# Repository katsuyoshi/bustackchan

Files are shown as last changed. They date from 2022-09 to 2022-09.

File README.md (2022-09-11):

# ﾊﾞｽﾀｯｸﾁｬﾝ (BUSTACK-chan)

BUSTACK-chan

[ｽﾀｯｸﾁｬﾝ](https://protopedia.net/prototype/2345)にインスパイアされて作りました。

ﾊﾞｽﾀｯｸﾁｬﾝ という名前の思いつきからのスタートでした。

protopediaのページも併せてご覧ください。

https://protopedia.net/prototype/3251

## 材料

|材料|数量|備考|
|:--|--:|:--|
|[M5Stack Basic]()|1||
|[M5Stack用NeoPixel互換 LEDテープ 10 cm](https://www.switch-science.com/catalog/5208/)|1||
|[M5Stack用GROVE互換ケーブル 10 cm](https://www.switch-science.com/catalog/5213/)|1||
|[ｽﾀｯｸﾁｬﾝの基板]()|1|ｽﾀｯｸﾁｬﾝの公開されているGithubページに[データ](https://github.com/meganetaaan/stack-chan/tree/main/schematics/m5-pantilt/gerber)があります。[nyaru lab](https://booth.pm/ja/items/4094998)さんが販売している様です。|
|[リチウムイオンポリマー電池](https://www.switch-science.com/catalog/3118/)|1||
|[M5Stack用2 x 15ピンヘッダ](https://www.switch-science.com/catalog/3654/)|1||
|その他ピンヘッダ、コンデンサ、抵抗など||[ｽﾀｯｸﾁｬﾝの基板組み立て](https://github.com/meganetaaan/stack-chan/blob/main/schematics/README_ja.md)説明のPWMサーボの項を参考にしてください。|

## 作り方

- 3Dプリンターでボディ、ヘッド、窓、シャーシ、タイヤを印刷します。
  |パーツ|備考|
  |:--|:--|
  |[ボディ](models/body%20v19.gcode)|加工が必要です。|
  |[ヘッド](models/head%20v4.gcode)||
  |[窓](models/window%20v2.gcode)|左右と後部の3つが組みになっています。|
  |[シャーシ](models/chassis3%20v6.gcode)||
  |[タイヤ](models/tire%20v3.gcode)|4本組みになってます。|

- ポディでM5StackのUSB-Cコネクターと電源ボタンの部分が塞がれているので、[発泡スチロールカッター](https://getnavi.jp/zakka/464317/)などでコネクターが差し込みできる様にボディにスリットを入れます。(*1)

- ボディに窓をはめる際は平やすりなどで窓枠の下の方を少々削って調整する必要があります。左右も若干削った方が良いかもしれません。窓をボディにはめ、ピッタリの場合はそのままで問題ありませんが、緩い場合は接着剤などを使ってください。

- 竹串か竹籤(φ2.5mm)を52mmの長さで切り2本用意します。

- シャーシの穴の空いているところに竹串を通し両端にタイヤを差し込みます。入りずらい場合は竹串の先端を少し削ってください。

- ｽﾀｯｸﾁｬﾝ基板を組み立てます。オリジナル[ｽﾀｯｸﾁｬﾝの基板組み立て](https://github.com/meganetaaan/stack-chan/blob/main/schematics/README_ja.md)説明のPWMサーボの項を参考に組み立てます。

- 基板をM5Stackに付けます。

- LEDテープをシャーシに付けます。(*2) マッチ箱くらいの物を貼り付けその側面にLEDテープを貼り付けます。

- リチウムイオンポリマー電池をその上に貼り付けます。

- GROVE互換ケーブルでLEDテープと基板を接続します。基板側はピッチが合わないのでケーブルを切断しコネクターをつける加工をし、J3ピンヘッダーにGND側を合わせて差し込みます。

- リチウムイオンポリマー電池を基板と接続します。

- M5Stackをシャーシーの先頭部に差し込みます。この時ボタンが上になる様にします。

- ボディをシャーシーに被せます。

- ヘッドをボディの穴に合わせて差し込みます。

- プログラムを書き込みます。PlatformIOを使っています。
  - 使用しているライブラリーはplatformio.iniをご覧ください。

*1 将来的にはモデルに反映したいと思っています。  
*2 将来的にはモデルに取り付け用の仕掛けをつけたいと思います。

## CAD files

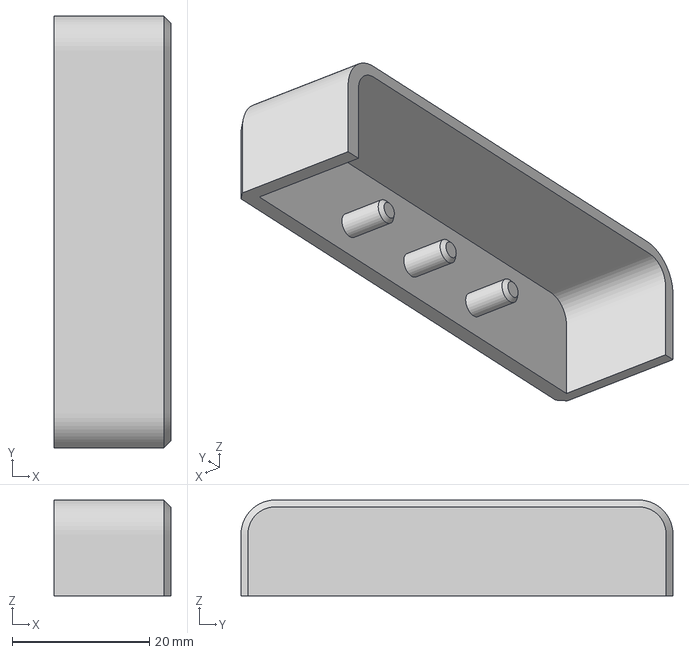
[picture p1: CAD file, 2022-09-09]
models/head v5.3mf
17.0 x 63.0 x 14.0 mm

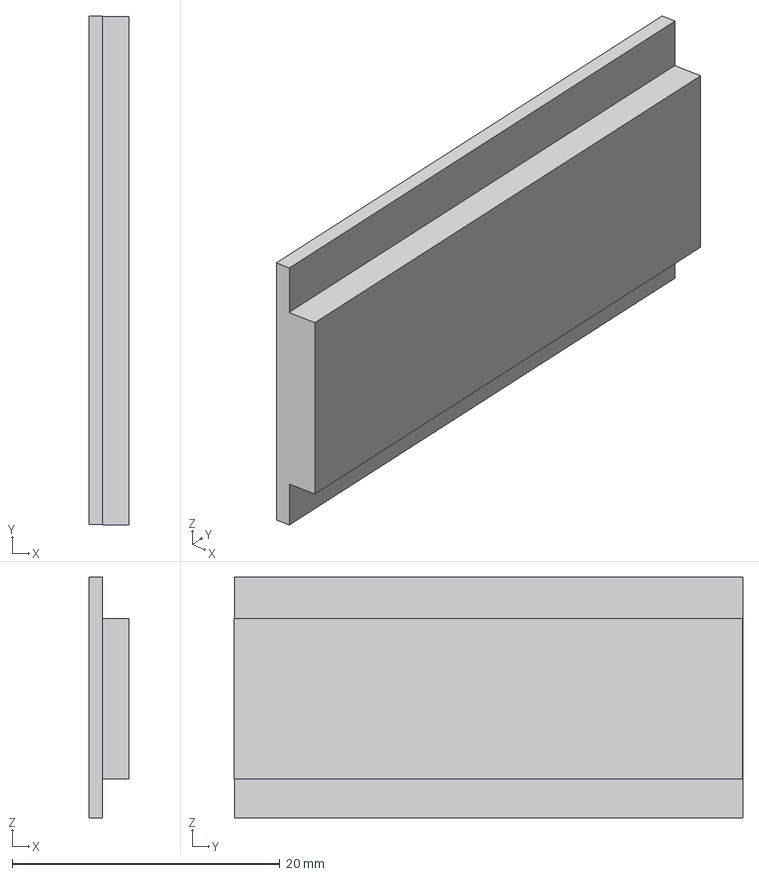
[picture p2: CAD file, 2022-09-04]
models/window2 v2.3mf
3.00 x 38.0 x 18.0 mm

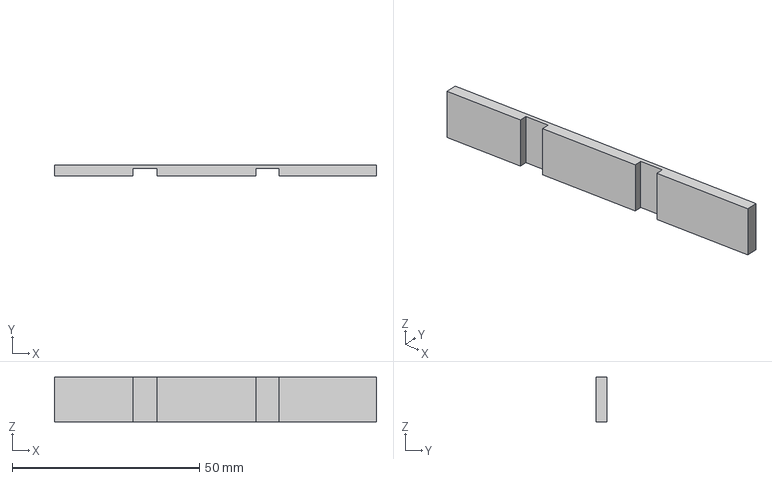
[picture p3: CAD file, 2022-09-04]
models/window1-left v2.3mf
86.0 x 3.00 x 12.0 mm

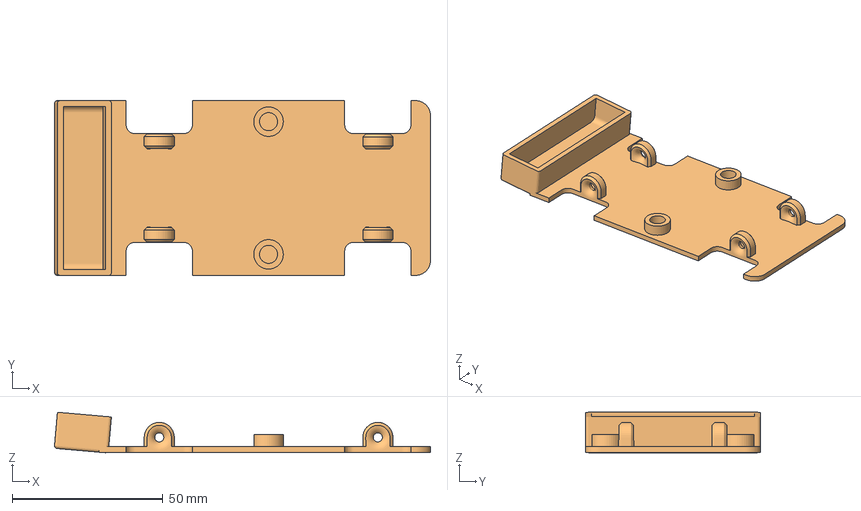
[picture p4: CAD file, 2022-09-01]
models/chassis3 v6.3mf
124.7 x 58.0 x 13.4 mm
ボディ1 x 2

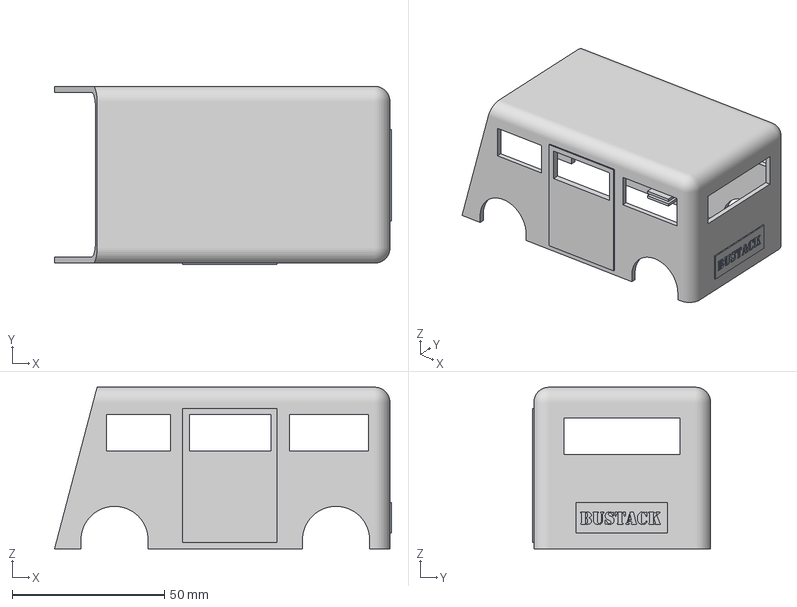
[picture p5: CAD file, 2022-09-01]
models/body v19.3mf
110.5 x 58.5 x 53.0 mm

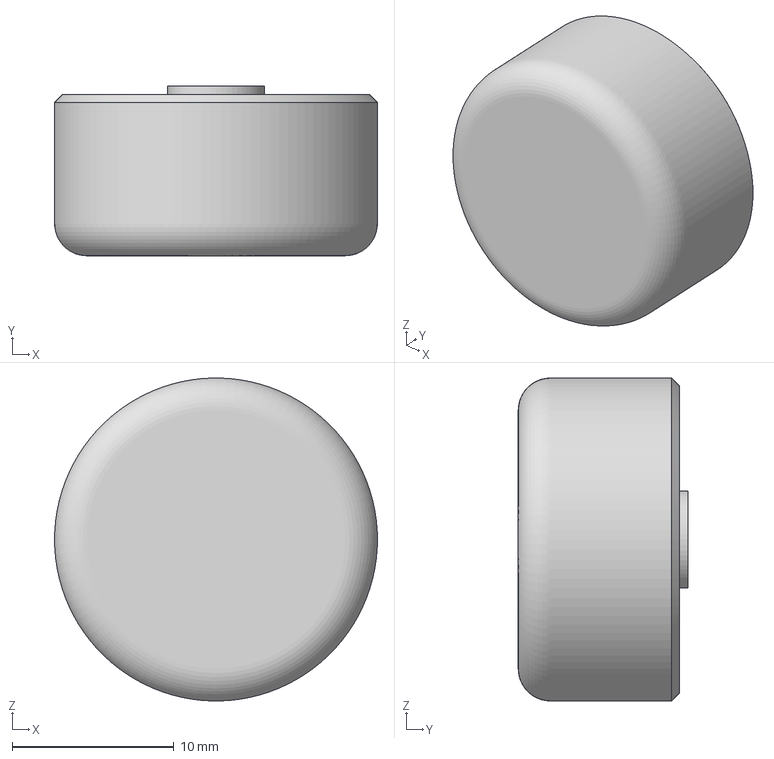
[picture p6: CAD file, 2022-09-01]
models/tire v3.3mf
20.0 x 10.5 x 20.0 mm

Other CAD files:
models/window1-right v2.3mf
models/head v4.3mf

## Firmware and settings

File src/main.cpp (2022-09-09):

#include <Arduino.h>
#include <M5Unified.h>
#include <WiFiMulti.h>
#include <Avatar.h>
#include <NeoPixelBus.h>
#include "ServoEasing.hpp"
#include "faces/bus_face.h"
#include <aquestalk.h>
#include "env.h"

using namespace m5avatar;

//******************************
// defines

//#define SERVO_PIN           5
#define PIXEL_PIN             2

//#define SERVO_START_DEGREE  90

#define colorSaturation 128


// LEDの点滅パターン
typedef enum led_pattern_id
 {
  LPNone,
  LPLeft,
  LPRight,
  LPStop,
};

// AquesTalkのフレーズ
typedef enum phrase_id {
  PHGreeting,
  PHJousha,
  PHOriru,
  PHSutakuNumaYuki,
  PHGrooto,
  PHArigato,
  PHTugiwa,
  PHTugiTomarimasu,
  PHTomarimasu,
  PHTrunLeft,
  PHTrunRight,
};

// 行き先表示
typedef enum heading_id {
  HDBustack,
  HDStackPond,
  HDGurutto,
};



//******************************
// Variables

// for avator
static Avatar avatar;
//static ServoEasing servo;
static ColorPalette cp;

// for WiFi
static WiFiMulti wifiMulti;


static double pi = atan(1.0) * 4.0;

// for AquesTalk
/// set M5Speaker virtual channel (0-7)
static constexpr uint8_t m5spk_virtual_channel = 0;
static constexpr uint8_t LEN_FRAME = 32;
static uint32_t workbuf[AQ_SIZE_WORKBUF];
static TaskHandle_t task_handle = nullptr;
volatile bool is_talking = false;

static int volume = 127;
static bool vol_up = true;
static bool vol_changing = false;

static phrase_id speaking_phrase = PHGreeting;

// @see: https://www.a-quest.com/demo/index.html
// 上記サイトで規則音声合成テキストを生成する。
// utilsのkana2romajiでローマ字に変換する。
//
// 例)
// 「どーも、バスタックちゃんです。」
//    |
//    V Convert
// 「ド'ーモ、バ'_ス/タ'ッ_クチャンデ_ス。」
//
// % ./kana2romaji "ド'ーモ、バ'_ス/タ'ッ_クチャンデ_ス。"
// #=> "do'-mo,ba'_su/ta'_kutyan;de_su."
//

static const char *phrases[] = {
  "do'-mo,ba'_su/ta'_kutyan;de_su.",
  "onorino+katawa/botan;o/o_sitekudasa'i.",
  "oorinokatawa/bo'tan;o/o_sitekudasa'i.",
  "kono/ba'suwa/_sutakku'numa/yu'kide_su.",
  "kono/ba'suwa/a_kitake'n;naio/syu-kaisuru/guru'to/a'_kitade_su.",
  "gozyo-sya/ari'gato-+gozaima'_sita.matano/goriyo-o/oma_ti/siteorima'_su.",
  "tugi'wa.",
  "tugi'/tomarima'_su.",
  "tomarima'_su.",
  "hidarini/magarima'_su.gotyu-ikudasa'i.",
  "migini/magarima'_su.gotyu-ikudasa'i.",
};

static const char *municipalities[] = {
  "higasinarusemura",
  "yuzawa'_si.",
  "ugo'mati",
  "yokote'_si.",
  "misato'tyo-",
  "daise'n;_si.",
  "sen;boku'_si.",
  "kazuno'_si.",
  "kosaka'mati",
  "o-date'_si.",
  "huzisato'mati",
  "happou'tyo-",
  "nosiro'_si.",
  "_kitaa_kita'_si.",
  "kamikoanimura",
  "mitane'tyo-",
  "oogatamura",
  "oga'_si.",
  "katagami'_si.",
  "ikawa'mati",
  "hatiro-gata'mati",
  "gozyo-me'mati",
  "a_kita'_si.",
  "yurihon;zyo'-_si.",
  "nikaho'si"
};


// for BUSTACK
volatile bool boarding = false;
volatile bool stop_requested = false;
static int next_time = 0;

static heading_id heading_for = HDBustack;

static const char *heading_titles[] = {
  "　　バスタックちゃん　　",
  "　　 スタック沼行き 　　",
  "　　　ぐるっと秋田　　　",
};

int interval_between_stops = 1;


// for LEDs
static led_pattern_id
 led_pat = LPNone;
const uint16_t PixelCount = 15;
const uint8_t AnimationChannels = 1;
NeoPixelBus<NeoGrbFeature, Neo800KbpsMethod> strip(PixelCount, PIXEL_PIN);

RgbColor red(colorSaturation, 0, 0);
RgbColor green(0, colorSaturation, 0);
RgbColor blue(0, 0, colorSaturation);
RgbColor yellow(colorSaturation, colorSaturation, 0);
RgbColor orange(colorSaturation, colorSaturation * 165 / 255, 0);
RgbColor white(colorSaturation);
RgbColor black(0);


// for NTP sync

time_t time_synced_at = 0;
uint32_t millis_since_time_synced;

const char* ntpServer = "ntp.nict.jp";
const long  gmtOffset_sec = 3600 * 9;
const int   daylightOffset_sec = 0;



//******************************
// functions

static void SetRandomSeed()
{
    uint32_t seed;

    // random works best with a seed that can use 31 bits
    // analogRead on a unconnected pin tends toward less than four bits
    seed = analogRead(0);
    vTaskDelay(1);

    for (int shifts = 3; shifts < 31; shifts += 3)
    {
        seed ^= analogRead(0) << shifts;
        vTaskDelay(1);
    }

    randomSeed(seed);
}


// for LEDs
static void set_left_led() {
  for (int i = 0; i < PixelCount; i++) {
    if (i >= 9) {
      strip.SetPixelColor(i, orange);
    } else {
      strip.SetPixelColor(i, black);
    }
  }
  strip.Show();
}

static void set_right_led() {
  for (int i = 0; i < PixelCount; i++) {
    if (i < 6) {
      strip.SetPixelColor(i, orange);
    } else {
      strip.SetPixelColor(i, black);
    }
  }
  strip.Show();
}

static void set_stop_led() {
  for (int i = 0; i < PixelCount; i++) {
    if (i >= 6 && i < 9) {
      strip.SetPixelColor(i, red);
    } else {
      strip.SetPixelColor(i, black);
    }
  }
  strip.Show();
}

static void set_blank_led() {
  for (int i = 0; i < PixelCount; i++) {
    strip.SetPixelColor(i, black);
  }
  strip.Show();
}

static void led_task(void*)
{
  strip.Begin();
  while(true) {
    switch(led_pat) {
      case LPLeft:
        set_left_led();
        vTaskDelay(250);
        set_blank_led();
        vTaskDelay(250);
        break;
      case LPRight:
        set_right_led();
        vTaskDelay(250);
        set_blank_led();
        vTaskDelay(250);
        break;
      case LPStop:
        set_stop_led();
        vTaskDelay(100);
        break;
      default:
        set_blank_led();
        vTaskDelay(10);
        break;
    }
  }
}



// for AquesTalk

static void talk_task(void*)
{
  int16_t wav[3][LEN_FRAME];
  int tri_index = 0;
  for (;;)
  {
    ulTaskNotifyTake( pdTRUE, portMAX_DELAY ); // wait notify
    while (is_talking)
    {
      uint16_t len;
      if (CAqTkPicoF_SyntheFrame(wav[tri_index], &len)) { is_talking = false; break; }
      M5.Speaker.playRaw(wav[tri_index], len, 8000, false, 1, m5spk_virtual_channel, false);
      tri_index = tri_index < 2 ? tri_index + 1 : 0;
    }
  }
}

static void lip_sync_task(void *args)
{
  DriveContext *ctx = reinterpret_cast<DriveContext *> (args);
  Avatar *avatar = ctx->getAvatar();
  while(true) {
    if (is_talking) {
      float open = random(0,99) / 100.00;
      avatar->setMouthOpenRatio(open);
    } else {
      avatar->setMouthOpenRatio(1.0);
    }
    vTaskDelay(5);
  }
}

/// 音声再生の終了を待機する;
static void waitAquesTalk(void)
{
  while (is_talking) { vTaskDelay(1); }
}

/// 音声再生を停止する;
static void stopAquesTalk(void)
{
  if (is_talking) { is_talking = false; vTaskDelay(1); }
}

/// 音声再生を開始する。(再生中の場合は中断して新たな音声再生を開始する) ;
static void playAquesTalk(const char *koe)
{
  stopAquesTalk();

  //M5.Display.printf("Play:%s\n", koe);

  int iret = CAqTkPicoF_SetKoe((const uint8_t*)koe, 100, 0xFFu);
  //if (iret) { M5.Display.println("ERR:CAqTkPicoF_SetKoe"); }

  is_talking = true;
  xTaskNotifyGive(task_handle);
}

void speak(phrase_id id) {
  speaking_phrase = id;
  playAquesTalk(phrases[id]);
}

void speak_next_stop() {

  // 停止ボタンが押されていたら停止アナウンスする
  if (stop_requested) {
    switch(random(3)) {
      case 0:
        speak(PHTrunLeft);
        led_pat = LPLeft;
        vTaskDelay(10000);
        break;
      case 1:
        speak(PHTrunRight);
        led_pat = LPRight;
        vTaskDelay(10000);
        break;
    }
    speak(PHTomarimasu);
    led_pat = LPStop;
    waitAquesTalk();
    vTaskDelay(1000);

    speak(PHArigato);
    waitAquesTalk();
    vTaskDelay(5000);

    led_pat = LPNone;
    stop_requested = false;
    boarding = false;

    const char *title = heading_titles[HDBustack];
    BusFace *face = (BusFace *)avatar.getFace();
    face->set_heading_title(title);
    face->set_stop_requested(stop_requested);
  }

  if (boarding) {
    int i = next_time % 24;
    if (i == 23) {
      speak(PHGrooto);
    } else {
      speak(PHTugiwa);
      waitAquesTalk();
      playAquesTalk(municipalities[i]);
      waitAquesTalk();
      vTaskDelay(500);
      speak(PHOriru);
    }
  }
}


// 乗車時処理

void get_on_for(heading_id id)
{
  const char *title = heading_titles[id];
  BusFace *face = (BusFace *)avatar.getFace();
  face->set_heading_title(title);

  switch(id) {
    case HDStackPond:
      speak(PHSutakuNumaYuki);
      break;
    case HDGurutto:
      speak(PHGrooto);
      break;
  }
  boarding = true;
}



// for time management

void syncTime() {
  configTime(0, 0, "pool.ntp.org");
  //configTime(gmtOffset_sec, daylightOffset_sec, ntpServer);

  Serial.print(F("Waiting for NTP time sync: "));
  time_t nowSecs = time(nullptr);
  while (nowSecs < 8 * 3600 * 2) {
    vTaskDelay(500);
    Serial.print(F("."));
    yield();
    nowSecs = time(nullptr);
  }

  Serial.println();
  struct tm timeinfo;
  gmtime_r(&nowSecs, &timeinfo);
  Serial.print(F("Current time: "));
  Serial.print(asctime(&timeinfo));
  Serial.print(timeinfo.tm_year);

  time_synced_at = mktime(&timeinfo);
  millis_since_time_synced = millis();
}

time_t now() {
  time_t n = (time_t)((millis() + 9 * 3600 * 1000 - (time_t)millis_since_time_synced) / 1000) + time_synced_at;
  return n;
}


int now_time() {
  time_t n = now();
  struct tm *t = gmtime(&n);
  return t->tm_hour * (60 / interval_between_stops)  + t->tm_min / interval_between_stops;
}

void update_next_time() {
  next_time = (now_time() + 1) % (24 * 60 / interval_between_stops);
}



// setup

void setup()
{
  auto cfg = M5.config();
  M5.begin(cfg);

  SetRandomSeed();

  // display MAC address
  uint8_t mac[6];
  esp_efuse_mac_get_default(mac);
  Serial.printf("¥nMAC Address = %02X:%02X:%02X:%02X:%02X:%02X\n", mac[0], mac[1], mac[2], mac[3], mac[4], mac[5]);

  xTaskCreateUniversal(talk_task, "talk_task", 4096, nullptr, 1, &task_handle, APP_CPU_NUM);

  M5.Speaker.setVolume(volume);

  WiFi.disconnect();
  WiFi.softAPdisconnect(true);
  WiFi.mode(WIFI_STA);
  wifiMulti.addAP(WIFI_SSID, WIFI_PASSWORD);
#ifdef WIFI_SSID2
  wifiMulti.addAP(WIFI_SSID2, WIFI_PASSWORD2);
#endif
  // If you have more points, repeat the above three lines like WIFI_SSID3, 4, 5 ...

  avatar.setRotation(pi);
  avatar.setFace(new BusFace());
  cp.set(COLOR_PRIMARY, TFT_WHITE);
  cp.set(COLOR_BACKGROUND, TFT_RED);
  cp.set(COLOR_SECONDARY, TFT_BLACK);
  avatar.setColorPalette(cp);
  avatar.init(1); // start drawing

  //if (servo.attach(SERVO_PIN, SERVO_START_DEGREE)) {
  //  Serial.print("Error attaching servo x");
  //}


  int iret = CAqTkPicoF_Init(workbuf, LEN_FRAME, AQUESTALK_KEY);
  if (iret) {
    M5.Display.println("ERR:CAqTkPicoF_Init");
  }

  xTaskCreatePinnedToCore(led_task, "led", 2048, NULL, 1, NULL, APP_CPU_NUM);
  avatar.addTask(lip_sync_task, "lipSync");


  vTaskDelay(5000);

  speak(PHGreeting);
  waitAquesTalk();
}

// loop

void loop()
{
  // 時刻の取得
  if (time_synced_at == 0) {
    if (wifiMulti.run() == WL_CONNECTED) {
      syncTime();
      update_next_time();
      speak(PHJousha);
    }
  }
  
  // 予定時刻になったらアナウンスする
  if (time_synced_at != 0) {
    if (now_time() == next_time) {
      if (boarding) {
        // 乗車時は次の停留所
        speak_next_stop();
      } else {
        // 未乗車時は乗車の案内
        speak(PHJousha);
      }
      update_next_time();
    }
  }



  // ボタンイベント
  M5.update();

  // 乗車時
  if (boarding) {
    if (M5.BtnA.wasReleased() || M5.BtnC.wasReleased()) {
      stop_requested = true;
      BusFace *face = (BusFace *)avatar.getFace();
      face->set_stop_requested(stop_requested);
      speak(PHTugiTomarimasu);
    }

  // 未乗車時
  } else {
    if (M5.BtnA.wasReleased()) {
      // スタック沼行き乗車
      get_on_for(HDStackPond);
    } else
    if (M5.BtnC.wasReleased()) {
      // ぐるっと秋田乗車
      get_on_for(HDGurutto);
    }
  }
  if (M5.BtnB.isHolding()) {
    vol_changing = true;
    if (vol_up) {
      volume = min(127, volume + 1);
    } else {
      volume = max(0, volume - 1);
    }
    M5.Speaker.setVolume(volume);
    vTaskDelay(10);
  }
  if (M5.BtnB.wasReleased()) {
    vol_changing = false;
    vol_up = !vol_up;
  }

  vTaskDelay(10);
}

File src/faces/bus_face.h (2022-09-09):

#ifndef BUS_FACE
#define BUS_FACE


#include <Face.h>
#include <Avatar.h>
#include "BoundingRect.h"
#include "DrawContext.h"
#include "Drawable.h"
#include "lgfx/Fonts/efont/lgfx_efont_ja.h"

using namespace m5avatar;

class BusMouth : public Drawable {
 private:
  uint16_t minWidth;
  uint16_t maxWidth;
  uint16_t minHeight;
  uint16_t maxHeight;

 public:
  BusMouth() : BusMouth(90, 90, 20, 20) {}
  BusMouth(uint16_t minWidth, uint16_t maxWidth, uint16_t minHeight,
           uint16_t maxHeight)
      : minWidth{minWidth},
        maxWidth{maxWidth},
        minHeight{minHeight},
        maxHeight{maxHeight} {}

  void draw(M5Canvas *spi, BoundingRect rect, DrawContext *ctx) {
    uint32_t primaryColor = ctx->getColorPalette()->get(COLOR_PRIMARY);
    uint32_t secondaryColor = ctx->getColorPalette()->get(COLOR_SECONDARY);
    uint32_t backgroundColor = ctx->getColorPalette()->get(COLOR_BACKGROUND);
    float breath = _min(1.0f, ctx->getBreath());
    float openRatio = ctx->getMouthOpenRatio();
    int h = minHeight + (maxHeight - minHeight) * openRatio;
    int w = minWidth + (maxWidth - minWidth) * (1 - openRatio);
    int x = rect.getLeft() - w / 2;
    int y = rect.getTop() - h / 2 + breath * 2;
    spi->fillRect(x, y, w, h, primaryColor);

    if (openRatio == 1.0) {
      spi->setCursor(x + 4, y + 4);                             // 座標を指定（x, y）
      spi->setTextSize(2.0);          // 文字倍率変更
      spi->setTextColor(secondaryColor, primaryColor);
      spi->println("BUSTACK");        // 表示内容をcanvasに準備
    }


    // 窓枠
    spi->fillRect(1, 40, 320 - 2, 120, primaryColor);
    if (stop_requested) {
      spi->setCursor(10, 65);
      spi->setFont(&fonts::lgfxJapanGothic_12);
      spi->setTextDatum( textdatum_t::top_center      );
      spi->setTextSize(5.0);
      spi->setTextColor(secondaryColor, primaryColor);
      spi->println("とまります");
    }

    // 行き先表示
    spi->setCursor(18, 4);                        // 座標を指定（x, y）
    spi->setFont(&fonts::lgfxJapanGothic_12);
    spi->setTextDatum( textdatum_t::top_center      );
    spi->setTextSize(2.0);            // 文字倍率変更
    spi->setTextColor(primaryColor, backgroundColor);
    spi->println(heading_title);                // 表示内容をcanvasに準備
  }

  void set_heading_title(const char *title) {
    heading_title = title;
  }

  void set_stop_requested(bool flag) {
    stop_requested = flag;
  }

  private:
    const char *heading_title = "　　バスタックちゃん　　";
    bool stop_requested = false;

};

class BusEye : public Drawable {
 private:
  uint16_t width;
  uint16_t height;
  uint16_t r;
  bool isLeft;

 public:
  // constructor
  BusEye(uint16_t width, uint16_t height, uint16_t r, bool isLeft)
        : width{width},
          height{height},
          r{r},
          isLeft{isLeft} {}
  //~Eye() = default;
  //Eye(const Eye &other) = default;
  //Eye &operator=(const Eye &other) = default;

  void draw(M5Canvas *spi, BoundingRect rect,
            DrawContext *ctx) {
    uint32_t primaryColor = ctx->getColorPalette()->get(COLOR_PRIMARY);
    rect.setSize(width, height);
    int x = rect.getLeft();
    int y = rect.getTop();
    int w = rect.getWidth();
    int h = rect.getHeight();
    spi->drawRect(x, y, w, h, primaryColor);

    {
      Expression exp = ctx->getExpression();
      uint32_t x = rect.getCenterX();
      uint32_t y = rect.getCenterY();
      Gaze g = ctx->getGaze();
      float openRatio = ctx->getEyeOpenRatio();
      uint32_t offsetX = g.getHorizontal() * 3 + (isLeft ? - 8 : 8);
      uint32_t offsetY = g.getVertical() * 3;
      uint32_t primaryColor = ctx->getColorPalette()->get(COLOR_PRIMARY);
      uint32_t backgroundColor = ctx->getColorDepth() == 1 ? 0 : ctx->getColorPalette()->get(COLOR_BACKGROUND);

      if (openRatio > 0) {
        spi->fillCircle(x + offsetX, y + offsetY, r, primaryColor);
        // TODO(meganetaaan): Refactor
        if (exp == Expression::Angry || exp == Expression::Sad) {
          int x0, y0, x1, y1, x2, y2;
          x0 = x + offsetX - r;
          y0 = y + offsetY - r;
          x1 = x0 + r * 2;
          y1 = y0;
          x2 = !isLeft != !(exp == Expression::Sad) ? x0 : x1;
          y2 = y0 + r;
          spi->fillTriangle(x0, y0, x1, y1, x2, y2, backgroundColor);
        }
        if (exp == Expression::Happy || exp == Expression::Sleepy) {
          int x0, y0, w, h;
          x0 = x + offsetX - r;
          y0 = y + offsetY - r;
          w = r * 2 + 4;
          h = r + 2;
          if (exp == Expression::Happy) {
            y0 += r;
            spi->fillCircle(x + offsetX, y + offsetY, r / 1.5, backgroundColor);
          }
          spi->fillRect(x0, y0, w, h, backgroundColor);
        }
      } else {
        int x1 = x - r + offsetX;
        int y1 = y - 2 + offsetY;
        int w = r * 2;
        int h = 4;
        spi->fillRect(x1, y1, w, h, primaryColor);
      }
    }

  }
};


class BusFace : public Face {
 public:
  BusFace()
      : Face(
          new BusMouth(90, 45, 5, 20), new BoundingRect(220, 163),
           new BusEye(100, 60, 24, false), new BoundingRect(170, 1),
           new BusEye(100, 60, 24, true), new BoundingRect(170, 220),
           new Eyeblow(32, 0, false), new BoundingRect(67, 96),
           new Eyeblow(32, 0, true), new BoundingRect(72, 230)) {}

  void set_heading_title(const char *title) {
    BusMouth *m = (BusMouth *)this->mouth;
    m->set_heading_title(title);
  }

  void set_stop_requested(bool flag) {
    BusMouth *m = (BusMouth *)this->mouth;
    m->set_stop_requested(flag);
  }

};

#endif

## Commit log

2022-09-01 bus face追加
2022-09-01 color depthを変えようとしたがうまくいかなかったので中断
2022-09-01 3dモデル追加
    [body v19.3mf, chassis3 v6.3mf, tire v3.3mf]
2022-09-03 aquestalk で話せる様になる。
2022-09-03 次の停留所をしゃべる様になる
2022-09-04 口の動きを追加
2022-09-04 停止ボタンを押して停止するまでのシーケンス追加
2022-09-04 窓に「とまります」と表示する様にした。
2022-09-04 頭部と窓のモデル追加
    [head v4.3mf, window1-left v2.3mf, window1-right v2.3mf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]
2022-09-09 volumeを変更できる様にした
2022-09-09 ヘッドのピンの長さを調整。ちょっと長くした。
    [head v5.3mf]
2022-09-09 行の順番整理
2022-09-09 サンプル設定の追加
2022-09-09 コメント行削除
2022-09-11 READMEを追加
